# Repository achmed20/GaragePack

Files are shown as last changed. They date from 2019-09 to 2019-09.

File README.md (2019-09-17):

# GaragePack
This is the firmware for a Garagedoor Opener which can be controled via Web or MQTT.
It uses a relay to trigger the Door switch, Ultrasonic sensor to figure out if the door is open/closed and if a car is parked beneath it and the optional PIR could be used as automatic lightswitch trigger or simple alarm sensor.

Parts i used:
* Wemos D1 mini
* Relay (KY-019) 
* Ultrasonic sensor (HC-SR04)
* (optional) PIR sensor (HC-SR501)
* (optional) Printed case (check the docs folder for the files)

# Building
All of the necceassary part are powered from the Wemos so all you have to do is solder them correctly together. 
* The relay goes to D5, 5V and GND to the Wemos respectivly
* The Ultrasonicsensor also gets his 5V and GND, Echo to D2 and Pulse to D1
* (optional) PIR gets powered as usual and the data Signal goes to D7

(You can change/find all the Pins in the main.cpp if you want to.)

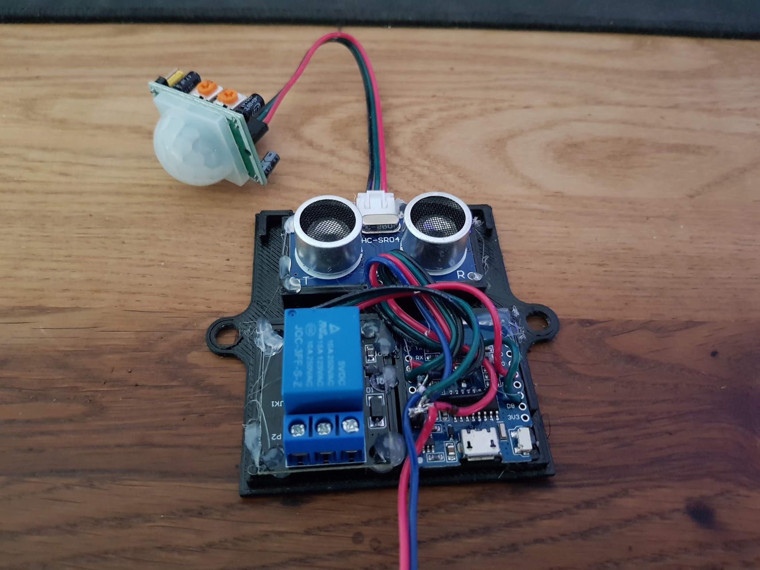
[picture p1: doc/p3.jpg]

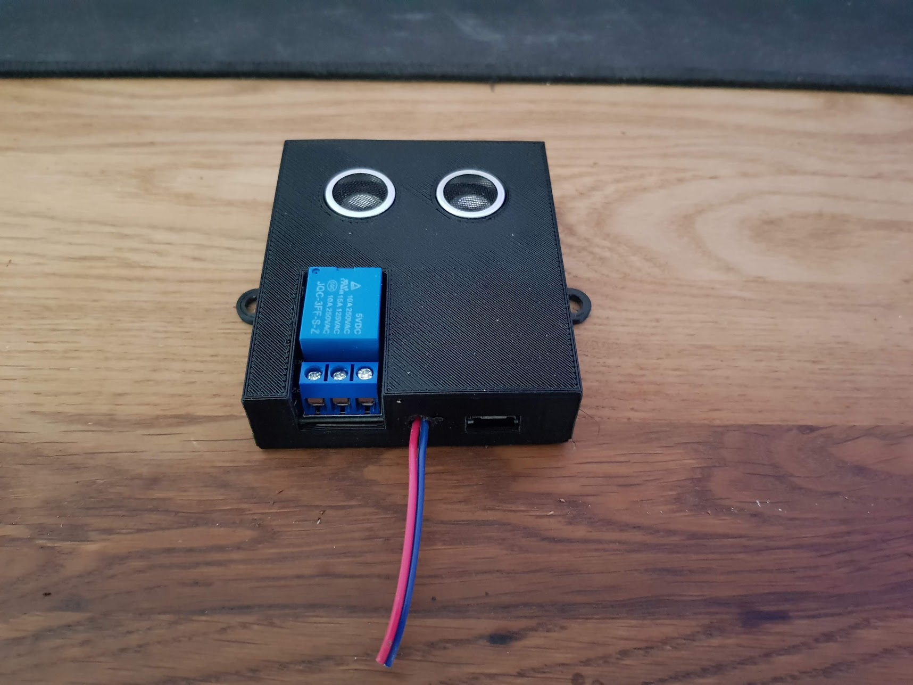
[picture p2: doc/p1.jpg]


# Flashing the firmware and Setup
Once powered up, its time to flash the firmware. I recommend Platform IO (VScode) for that. Clone this repo and load it into PlatformIO.

* Click on the Platform IO button (Bee head in the left menu)
* Click "Update project Libraries" to make it download all neccassary libs
* click "Upload File System Image"
* click "Upload"

Thats pretty much it. If you click monitor now, you should be able to see some information in the terminal. The ESP should now start in Setup mode meaning you can connect to it via wifi.

* Search your available Wifi's for "GaragePackSetup" and connect to it
* once connected, open your Browser and connect to "http://192.168.4.1". the UI should now open
* click on the Cog symbol on the top right and enter your WIFI credentials, set a name Hostname and hit "save"
* the ESP should now do a reboot and should be available under "http://[hostname]"

# Usage

Test this before you mount it. The door (pulse) switch should go to the to left screw terminals. If you have a Toggle switch, you might need all 3 screw terminals.

Once tested, you need to mount it above your Garagedoor, so that the ultrasonic sensor is blocked, once the door is open.

## Web
Click the large icon and you should hear the relay trigger, thats pretty much it.

## MQTT
If you set a MQTT server, all state changes will be submitted to you MQTT server

**MQTT publish:** home/[hostname]/state
```
{"open":false,"car":false,"motion":false,"distance":296,"lastupdate":36645}
```
This is how a published message looks like

**MQTT commands:** home/[hostname]/cmnd
```
{command:"open", value:"On"}
```
You can send this command to this channel to open / close your door. NOTE: it wont matter if the value is "on" or "off", if the relay is set to pulse mode, the relay will trigger either way.

## Setup Mode
If you need to change the Wifi credentials and you are not able to change them using the UI, you can bring the Garapack back into Setupmode, by blocking the sensors, lower then 10cm for 10 seconds. If your closed garagedoor  is  closer then 10cm, you will need to change the "maxDistanceToConfig" in the main.cpp

## Wifi errors
If a Wifi connection is lost, the ESP will restart. if its still not able to connect, it will perform a reboot every 5 minutes until its able to connect.

## Firmware update
You can upload a new firmware remotely using this URL: **http://[yourhostname]/update**

Note: This will not overwrite your current settings.

## UI
I Like simplicity which is why the UI is pretty barebone and fully responsive.

Once you Open the web interface, you will be greeted by this screen. 

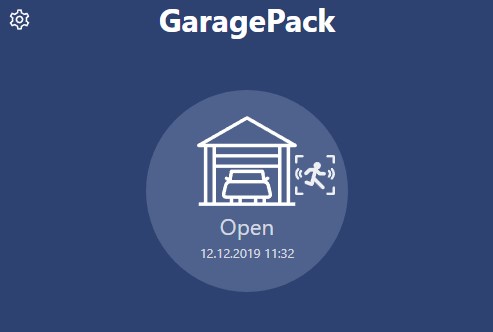
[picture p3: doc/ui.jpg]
UI


It shows you the current state of the Garagedoor and if movement is detected. A simple klick/touch on the Icon will trigger the relay and open / close the door, depending on its current state. The upper right icon will lead you to the Settings page

## Settings

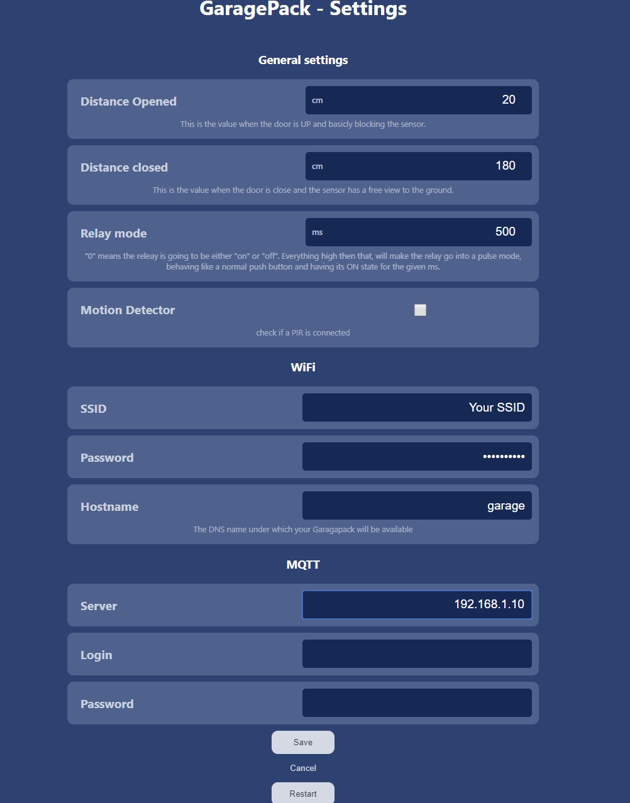
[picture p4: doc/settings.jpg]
Settings


## ToDo

* add MQTT port config
* remote update spiffs
* HomeASSISTANT autodetect (https://www.home-assistant.io/docs/mqtt/discovery/)

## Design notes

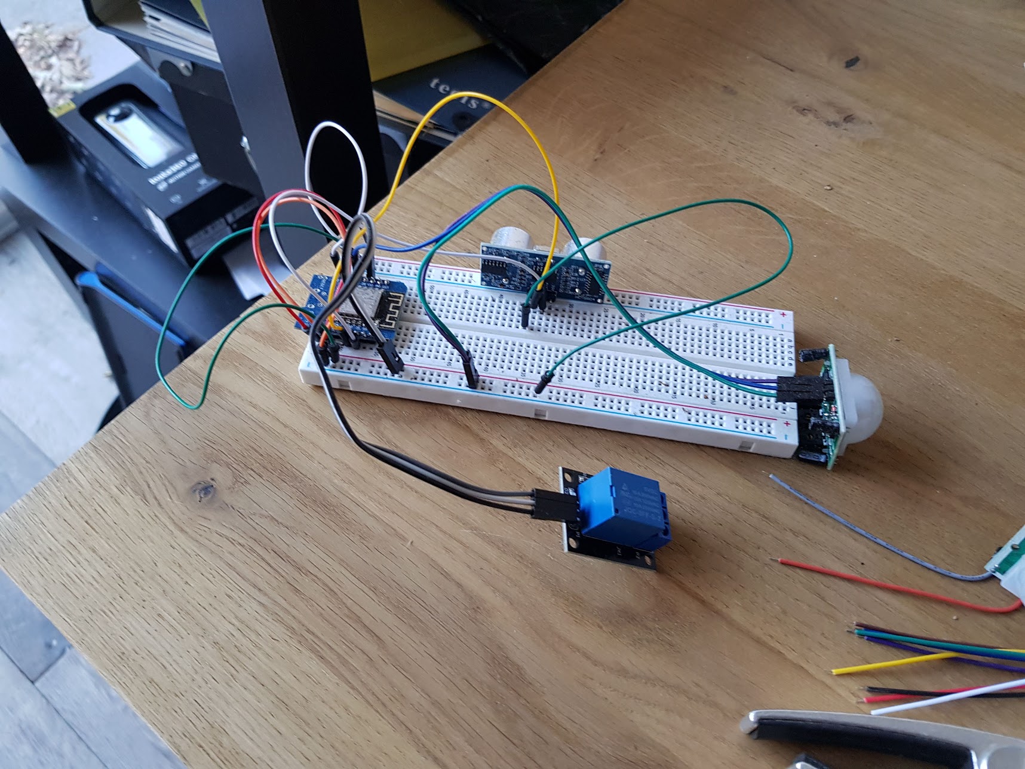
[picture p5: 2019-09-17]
doc/prototype.jpg

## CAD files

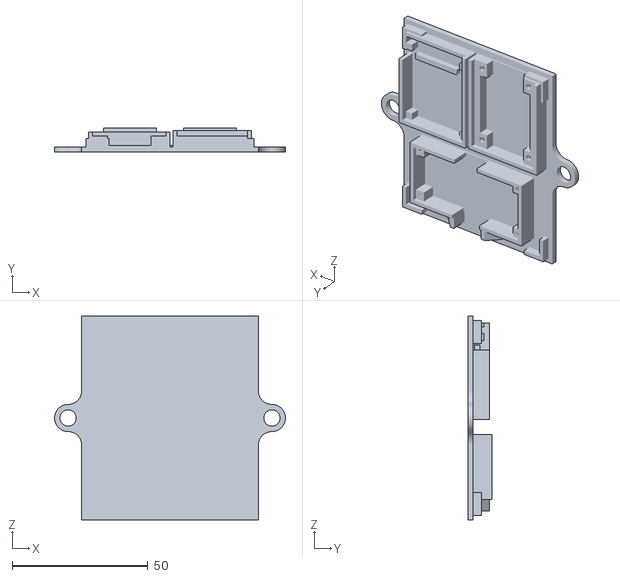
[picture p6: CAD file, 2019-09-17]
doc/case_bottom.stl
85.0 x 9.00 x 75.0

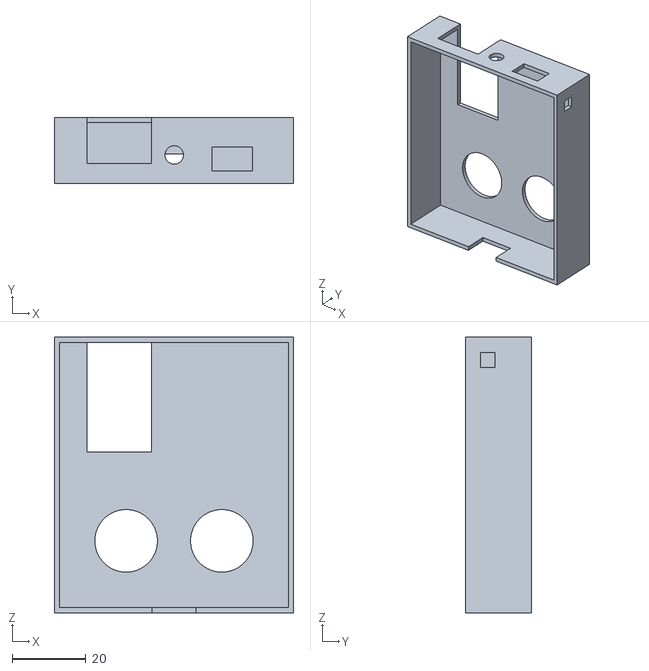
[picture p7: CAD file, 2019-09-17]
doc/case_top.stl
65.0 x 18.0 x 75.0

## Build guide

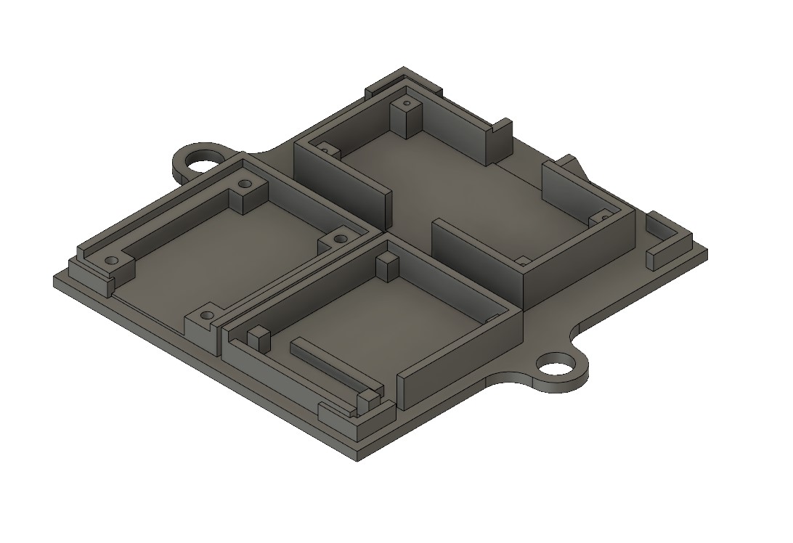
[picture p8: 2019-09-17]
doc/printed_case_bottom.jpg

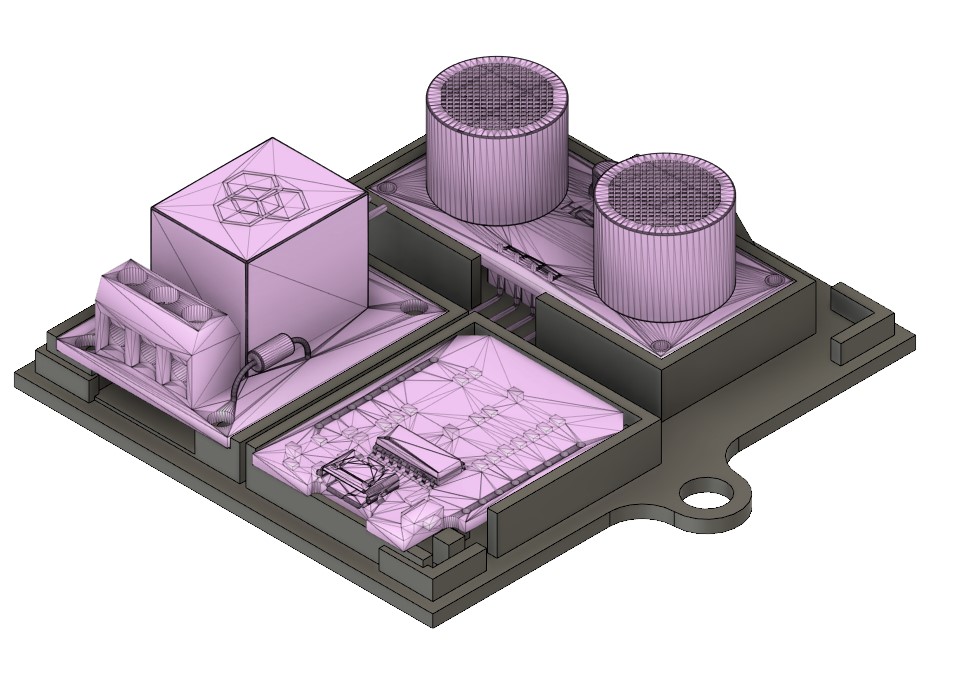
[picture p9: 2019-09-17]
doc/printed_case_bottom2.jpg

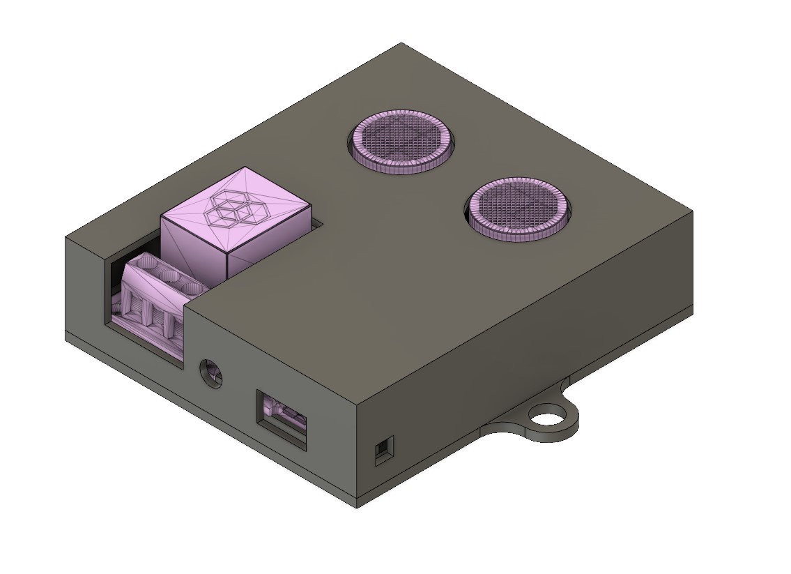
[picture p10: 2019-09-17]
doc/printed_case_full2.jpg

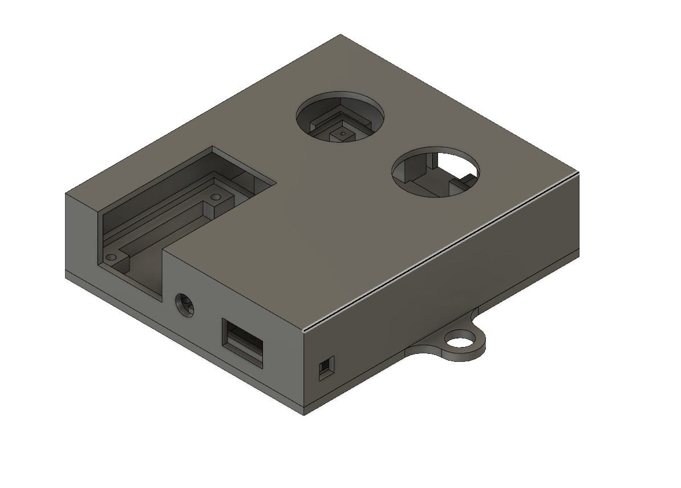
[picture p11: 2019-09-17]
doc/printed_case_full.jpg

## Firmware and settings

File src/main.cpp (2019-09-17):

#include <Arduino.h>

#include <Ultrasonic.h>
#include <WiFiUdp.h>
#include <NTPClient.h>

#include <structs.h>
#include <garagestatus.h>
#include <asyncwebserver.h>
#include <mqtt.h>

Settings settings;
// const char* ssid = "BND Servicemobil";
// const char* password = "bfb0zekczb";

// defines pins numbers
int relay = D5;
int pirPin = D7;
Ultrasonic ultrasonic1(D1, D2, 20000UL);

// unsigned long int relayMode = 500;  //0=toggle, >0=delay ms for push button emulation
bool relayState = LOW;
unsigned long relayTimer = 0;

const char* version = "0.8";

bool debug = false;
sensordata sensors;
int prevChecksum = 9;
unsigned long nextScan=0;
unsigned long scanTime = 100;

bool restartRequired = false;  
const uint setupAddr = 0;

// if ultrasonic sensor is <maxDistanceToConfig> for <configAry[seconds]>, start config portal
int maxDistanceToConfig = 10; 
unsigned int SecondsToConfig = 10;
unsigned long configStartTime = 0;

// failsafes and wifi checking values
unsigned int restartAfterWifiError = 300;
unsigned long timeToRestart = 0;
GarageStatus garagestatus;

WiFiUDP ntpUDP;
NTPClient timeClient(ntpUDP, "europe.pool.ntp.org", 3600, 60000);
String currentTime = "";

// -------------------- internal functions ---------------------
bool saveSettings(Settings sd){
  File file = SPIFFS.open("/settings.json", "w");
  if(!file){
     Serial.println("There was an error opening the file for writing");
     return false;
  }
  if(file.print(SettingsToJson(sd))) {
    Serial.println("Settings written");
  }else {
      Serial.println("writing settings failed");
      return false;
  }
  return true;

}

int getDistance() { 
  return ultrasonic1.read(CM);
}

bool getMotion(){
  int val = digitalRead(pirPin);
  //low = no motion, high = motion
  if (val == LOW)
  {
    return false;
  }
  return true;
}

void checkRelay(){
    if(relayTimer>0 && millis() > relayTimer){
      Serial.println("{relay: false, mode: "+String(settings.relayMode)+"}");
      digitalWrite(relay, LOW);
      relayTimer = 0;
    }
}

bool toggleRelay(int state){
  bool cState = false;
  if(settings.relayMode==0){
    switch (state) {
      case 0:
        cState = LOW;
        break;
      case 1:
        cState = HIGH;
        break;
      case 2:
        cState = !relayState;
        break;
    }
    relayState = cState;
    digitalWrite(relay, cState);
    return cState;
  } else {

      Serial.println("{relay: true, mode: "+String(settings.relayMode)+"}");
    digitalWrite(relay, HIGH);
    relayTimer = millis() + settings.relayMode;
    return true;
  }
}

int getStatusChecksum(Status s){
  int ret = 0;
  if(s.open){
    ret+=1;
  }
  if(s.car){
    ret+=10;
  }
  if(s.motion){
    ret+=100;
  }
  return ret;
}

// ------------------------------ Setup -------------------------------------
void setup() {
  Serial.begin(115200); // Starts the serial communication
  
  Serial.print("Garagepack Version ");
  Serial.println(version);

  pinMode(relay, OUTPUT);

  //read config
  SPIFFS.begin();
  File f = SPIFFS.open("/settings.json", "r");
  if (!f) {
     Serial.println("Loading settings failed! Either the SPIFFS filesystem was not flashed or something went horribly wrong.");
  }else {
    String jdata = f.readString();
    settings = JsonToSettings(jdata);

    Serial.println("Loading settings");
    
    garagestatus.distanceDoorOpen = settings.doorDistanceOpen;
    garagestatus.distanceDoorClosed = settings.doorDistanceClosed;
   
  } 

  // delay(1000);
  startWifi();
  Serial.println(WiFi.status());
  if(WiFi.status() != WL_CONNECTED){
    Serial.println("Wifi connection error! restarting in seconds " + String(restartAfterWifiError));
    timeToRestart = millis() + (restartAfterWifiError * 1000);
  }

  timeClient.begin();
  if(String(settings.mqttHost)!=""){
    setupMqtt();
  } else {
    Serial.println("MQTT host not set, skipping");
  }
}

// ------------------ main loop

void loop() {
  
  // check wifi
  if ( !settings.runSetup and (WiFi.status() == WL_CONNECTION_LOST || WiFi.status() == WL_DISCONNECTED))
  {
    Serial.println("connection to WiFi lost, restarting");
    restartRequired = true;
  }

  // check for restart flag or restart timer
  if (restartRequired || (timeToRestart>0 and timeToRestart< millis() )){  // check the flag here to determine if a restart is required
    Serial.printf("Restarting ESP\n\r");
    restartRequired = false;
    ESP.restart();
  }

  if(String(settings.mqttHost)!=""){
    mqttLoop();
  }

  // get time for mqtt and mserial messages;
  currentTime = timeClient.getFormattedTime();

  bool stable = false;
  checkRelay(); // cant use delay because of asyncwebserver
  sensors.lastUpdate = millis();

  // if PIR enabled, initialize
  if(settings.hasPIR){
    sensors.motion = getMotion();
  }

  //dont scan for distance all the time (echos?)
  if(nextScan<=millis()){
    nextScan = millis() + scanTime;
    sensors.distance = getDistance();
    stable = garagestatus.feed(sensors);
    if(debug){
      Serial.println(sensors.distance);
    }
  }

  // -----  start config? check here
  if(sensors.distance <= maxDistanceToConfig && sensors.distance>0){
    if(configStartTime==0){
      configStartTime = millis();
      Serial.println("Config mode initializing");
    } 
  } else if (configStartTime>0) {
      Serial.println("Config mode cancled");
      configStartTime = 0;
  }
  
  // if scandistance lower <maxDistanceToConfig> for <SecondsToConfig> seconds
  // start config mode
  if(configStartTime >0 && (millis()-configStartTime)/1000 >= SecondsToConfig){
    configStartTime = 0;
    Serial.println("Starting Config Portal)");
    settings.runSetup = true; //save in settings, will be reset once settings have been saved via UI aggain
    saveSettings(settings);
    restartRequired = true;
  }
  // -------------------------------


  if(stable){ //only submit values if readings are stable
    String strStatus = StatusToJson(garagestatus.getStatus());
    char charStatus[255];
    strStatus.toCharArray(charStatus, 255);

    if(getStatusChecksum(garagestatus.getStatus()) != prevChecksum){
      mqttPublish(charStatus);
      Serial.println(strStatus);
      WifiSendtatus(strStatus);
    }
    prevChecksum = getStatusChecksum(garagestatus.getStatus());

  }

}
